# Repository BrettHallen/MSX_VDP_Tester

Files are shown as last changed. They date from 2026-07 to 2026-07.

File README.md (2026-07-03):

# Yamaha V99x8 Tester for MSX
Simple Arduino sketch & PCB to test if a V9958 is real.<br>

PCB is designed & Arduino sketch generated (by Claude) but nothing is tested or sanity checked yet (3/Jul/2026).<br>

Idea is to query the "identification number" of the chip from bits 1-5 of status register S#1:
- 0 = V9938
- 1 = V9948
- 2 = V9958
- 3 = V9968
- 4 = V9978

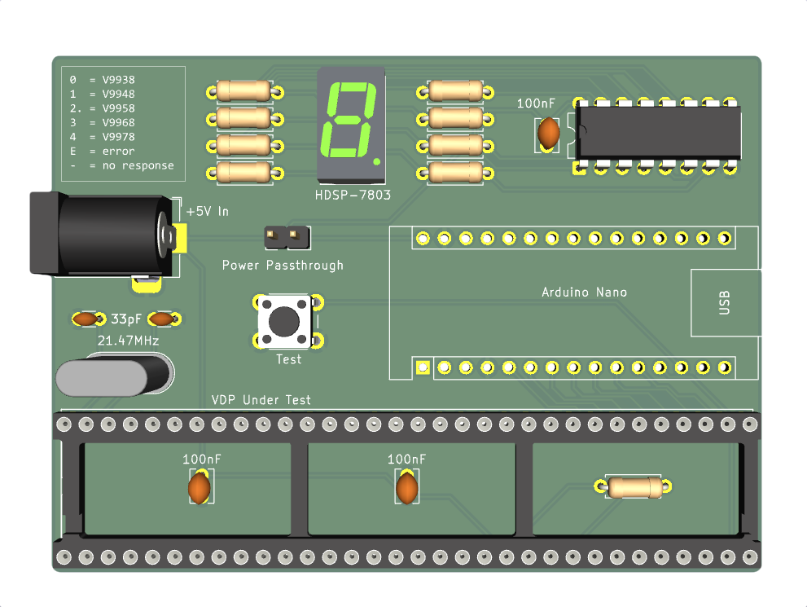
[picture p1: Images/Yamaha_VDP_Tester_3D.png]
3D of PCB


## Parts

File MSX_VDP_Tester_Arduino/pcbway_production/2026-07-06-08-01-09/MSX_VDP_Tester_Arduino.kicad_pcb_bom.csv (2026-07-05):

Designator | Quantity | Value | Footprint | Package | MPN | DNP | Mount_Type | Description | KiLib_Generator
A1 | 1 | Arduino Nano | Arduino_Nano |  |  |  | tht | Socket for Arduino Nano
C1, C2, C3 | 3 | 100nF | C_Disc_D3.8mm_W2.6mm_P2.50mm |  |  |  | tht | Unpolarized capacitor | capacitor/THT/other
C4, C5 | 2 | 33pF | C_Disc_D3.0mm_W1.6mm_P2.50mm |  |  |  | tht | Unpolarized capacitor | capacitor/THT/other
J1 | 1 | VDP Under Test | DIPS1905W50P178L5730H420Q64N |  |  |  | tht | Generic connector, double row, 02x32, counter clockwise pin numbering scheme (similar to DIP package numbering), script generated (kicad-library-utils/schlib/autogen/connector/)
J2 | 1 | +5V In | BarrelJack_Horizontal |  |  |  | tht | DC Barrel Jack
J3 | 1 | Power Passthrough | PinHeader_1x02_P2.54mm_Vertical |  |  |  | tht | Generic connector, single row, 01x02, script generated (kicad-library-utils/schlib/autogen/connector/) | connector/pin_header_socket
R1 | 1 | 10KΩ | R_Axial_DIN0207_L6.3mm_D2.5mm_P7.62mm_Horizontal |  |  |  | tht | Resistor | resistor/THT
R2, R3, R4, R5, R6, R7, R8, R9 | 8 | 470Ω | R_Axial_DIN0207_L6.3mm_D2.5mm_P7.62mm_Horizontal |  |  |  | tht | Resistor | resistor/THT
SW1 | 1 | Test | SW_PUSH_6mm |  |  |  | tht | Push button switch, generic, two pins
U1 | 1 | 74LS595 | DIP-16_W7.62mm |  |  |  | tht | 8-bit serial in/out Shift Register 3-State Outputs | package/DIP/legacy
U2 | 1 | HDSP-7803 | HDSP-7801 |  |  |  | tht | One digit 7 segment green, common cathode
Y1 | 1 | 21.47MHz | Crystal_HC49-U_Vertical |  |  |  | tht | Two pin crystal | crystal_resonator_oscillator

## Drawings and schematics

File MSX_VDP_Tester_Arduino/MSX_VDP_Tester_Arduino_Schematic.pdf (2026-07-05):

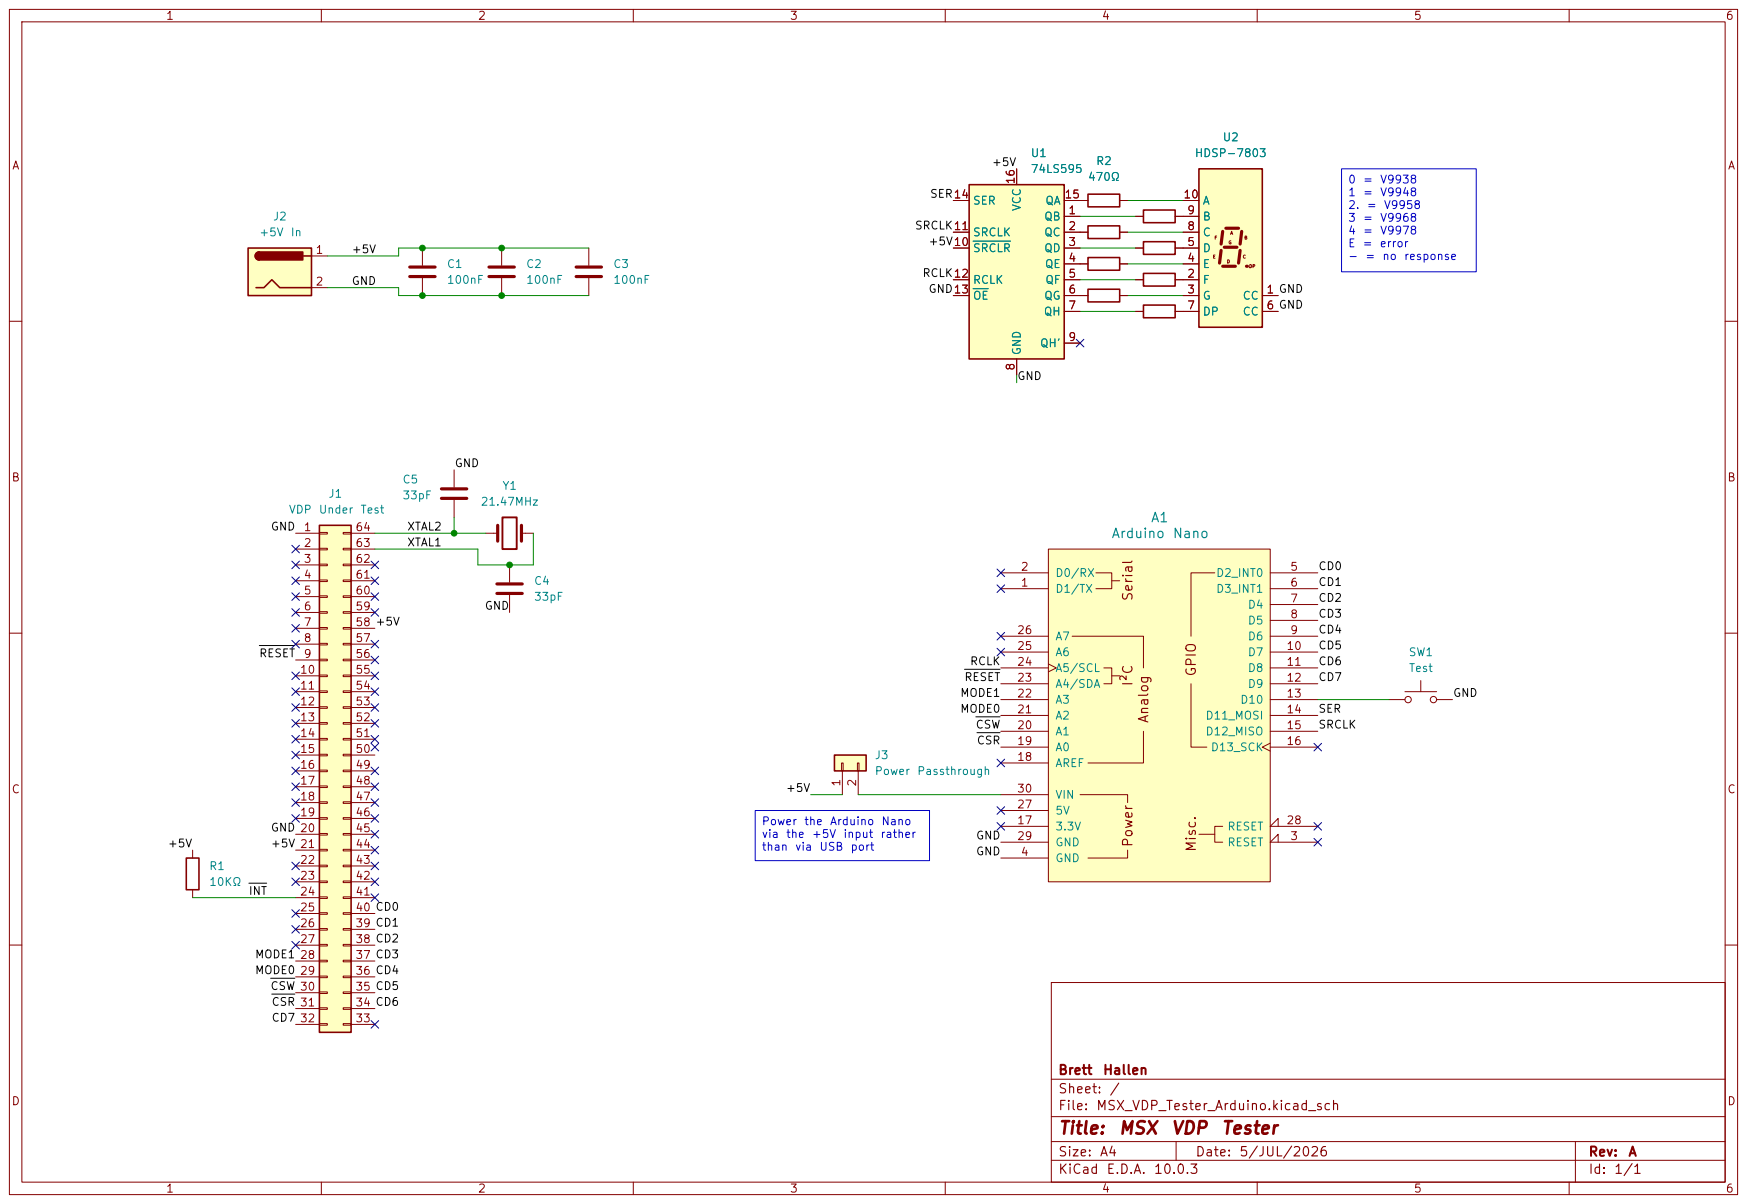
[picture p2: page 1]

SRCLR 10 SRCLK 11 RCLK 12 OE 13

E = error - = no response Power the Arduino Nano

via the +5V input rather
than via USB port

Brett Hallen
Sheet: /
File: MSX_VDP_Tester_Arduino.kicad_sch
Title: MSX VDP Tester

Size: A4 | Rev: A
KiCad E.D.A. 10.0.3 | Id: 1/1

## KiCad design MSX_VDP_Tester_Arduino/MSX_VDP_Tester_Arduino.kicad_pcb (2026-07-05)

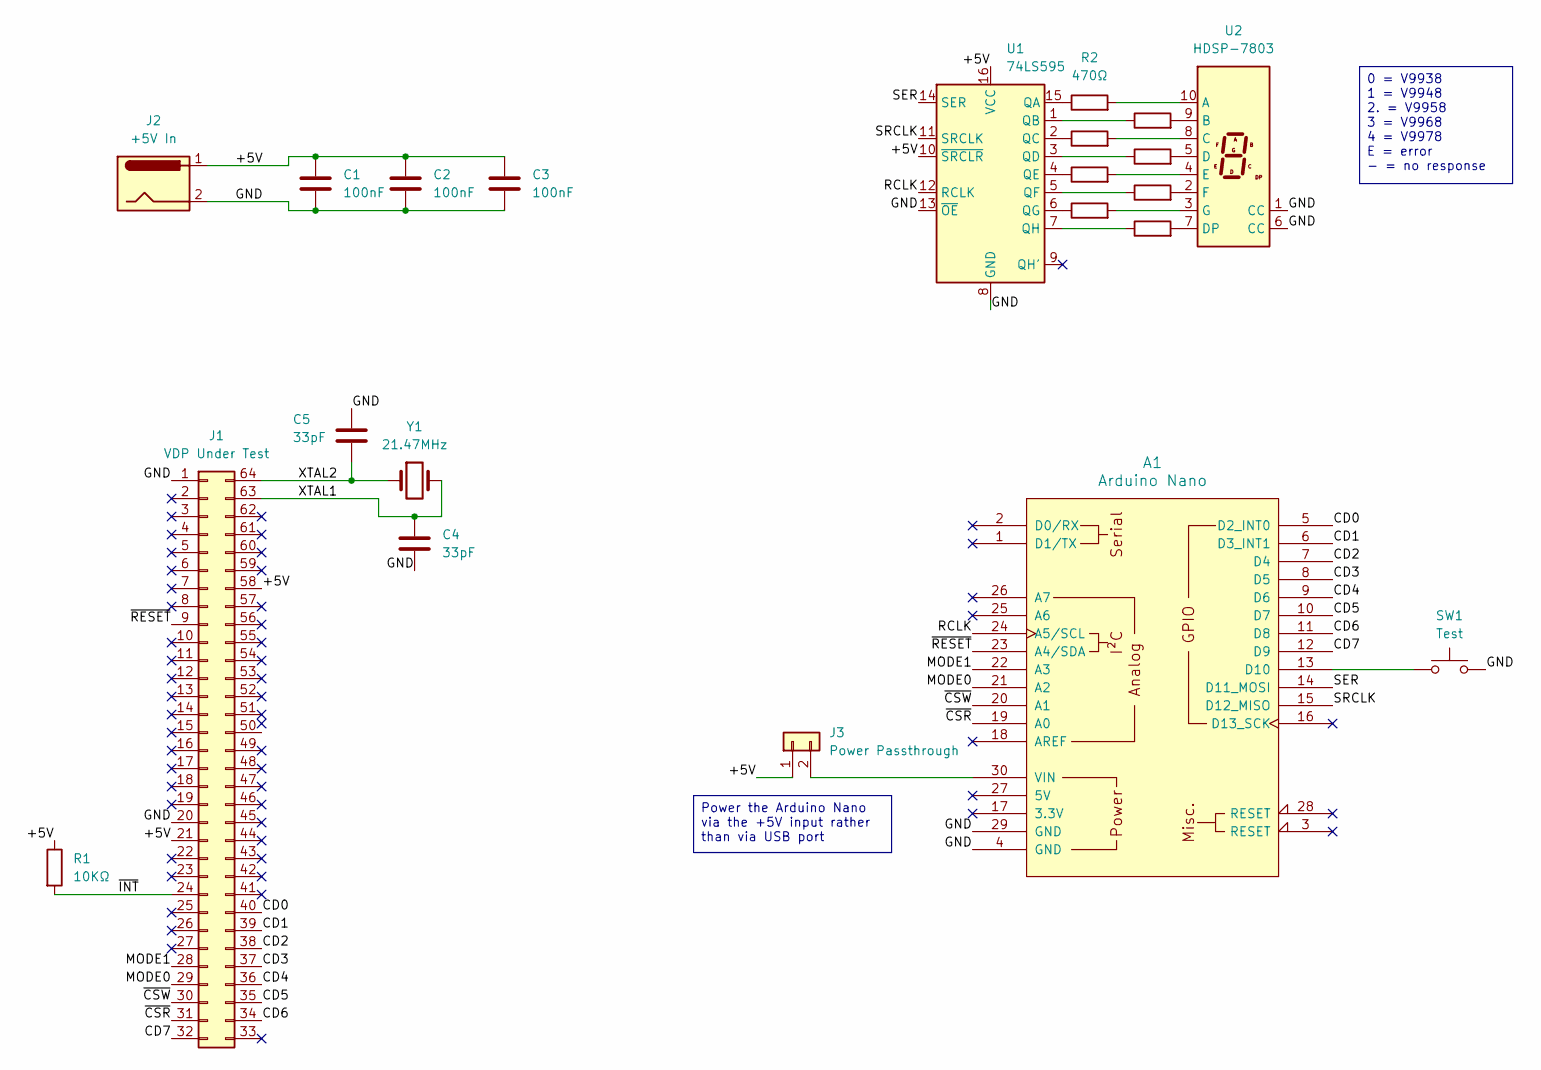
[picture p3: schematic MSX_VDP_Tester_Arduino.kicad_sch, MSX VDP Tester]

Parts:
A1: Arduino Nano; Arduino_Nano
C1, C2, C3: 100nF; C_Disc_D3.8mm_W2.6mm_P2.50mm
C4, C5: 33pF; C_Disc_D3.0mm_W1.6mm_P2.50mm
J1: VDP Under Test; DIPS1905W50P178L5730H420Q64N
J2: +5V In; BarrelJack_Horizontal
J3: Power Passthrough; PinHeader_1x02_P2.54mm_Vertical
R1: 10KΩ; R_Axial_DIN0207_L6.3mm_D2.5mm_P7.62mm_Horizontal
R2, R3, R4, R5, R6, R7, R8, R9: 470Ω; R_Axial_DIN0207_L6.3mm_D2.5mm_P7.62mm_Horizontal
SW1: Test; SW_PUSH_6mm
U1: 74LS595; DIP-16_W7.62mm
U2: HDSP-7803; HDSP-7801
Y1: 21.47MHz; Crystal_HC49-U_Vertical

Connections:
/+5V: C1.1, C2.1, C3.1, J1.21, J1.58, J2.1, J3.1, R1.1, U1.10 (~SRCLR), U1.16 (VCC)
/CD0: A1.5 (D2_INT0), J1.40
/CD1: A1.6 (D3_INT1), J1.39
/CD2: A1.7 (D4), J1.38
/CD3: A1.8 (D5), J1.37
/CD4: A1.9 (D6), J1.36
/CD5: A1.10 (D7), J1.35
/CD6: A1.11 (D8), J1.34
/CD7: A1.12 (D9), J1.32
/GND: A1.4 (GND), A1.29 (GND), C1.2, C2.2, C3.2, C4.2, C5.2, J1.1, J1.20, J2.2, SW1.2, U1.8 (GND), U1.13 (~OE), U2.1 (CC), U2.6 (CC)
/MODE0: A1.21 (A2), J1.29
/MODE1: A1.22 (A3), J1.28
/RCLK: A1.24 (A5/SCL), U1.12 (RCLK)
/SER: A1.14 (D11_MOSI), U1.14 (SER)
/SRCLK: A1.15 (D12_MISO), U1.11 (SRCLK)
/XTAL1: C4.1, J1.63, Y1.2
/XTAL2: C5.1, J1.64, Y1.1
/~CSR: A1.19 (A0), J1.31
/~CSW: A1.20 (A1), J1.30
/~INT: J1.24, R1.2
/~RESET: A1.23 (A4/SDA), J1.9
unnamed: A1.13 (D10), SW1.1
unnamed: A1.30 (VIN), J3.2
unnamed: R2.1, U1.15 (QA)
unnamed: R3.1, U1.1 (QB)
unnamed: R4.1, U1.2 (QC)
unnamed: R5.1, U1.3 (QD)
unnamed: R6.1, U1.4 (QE)
unnamed: R7.1, U1.5 (QF)
unnamed: R8.1, U1.6 (QG)
unnamed: R9.1, U1.7 (QH)
unnamed: R2.2, U2.10 (A)
unnamed: R3.2, U2.9 (B)
unnamed: R4.2, U2.8 (C)
unnamed: R5.2, U2.5 (D)
unnamed: R9.2, U2.7 (DP)
unnamed: R6.2, U2.4 (E)
unnamed: R7.2, U2.2 (F)
unnamed: R8.2, U2.3 (G)

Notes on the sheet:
Power the Arduino Nano via the +5V input rather than via USB port
0 = V9938 1 = V9948 2. = V9958 3 = V9968 4 = V9978 E = error - = no response

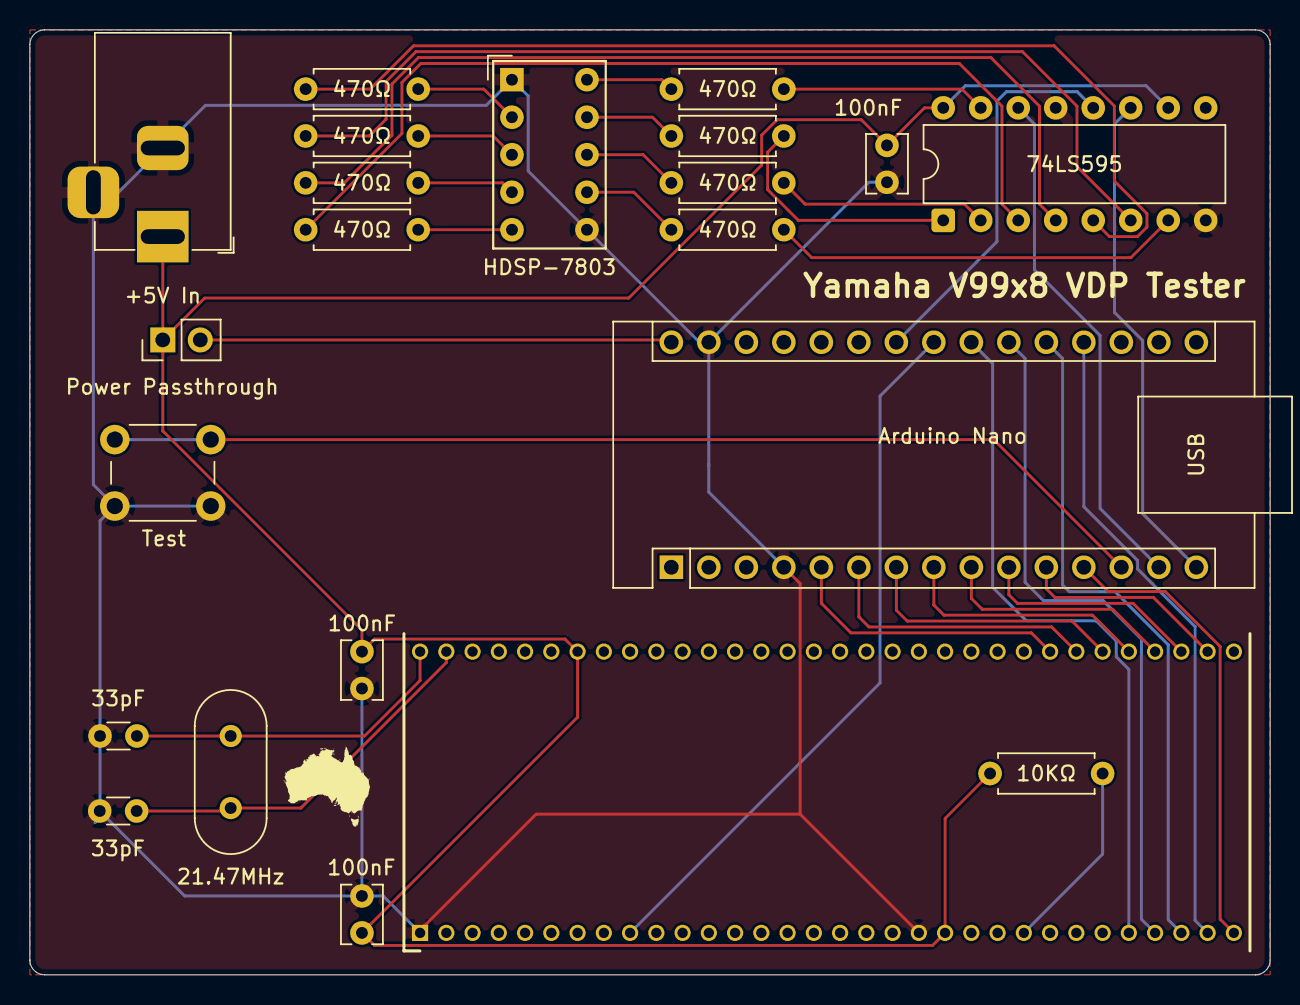
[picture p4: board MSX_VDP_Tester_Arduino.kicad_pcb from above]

Board: 2 copper layers, 84.0 x 64.0 mm, 22 parts (0 on the bottom side), 39 nets.

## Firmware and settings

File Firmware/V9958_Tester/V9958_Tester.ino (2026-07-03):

/* NOTE! Generated by Claude */
/* Not yet reviewed, cleaned up or even tested */
/* Brett Hallen, 3/Jul/2026 */

/*
 * ============================================================================
 *  V9958 / V9938 VDP Authenticity Tester  --  ARDUINO UNO / NANO (ATmega328P)
 *
 *  Uno and Nano share the ATmega328P, so the pin map and direct-port code are
 *  identical. NOTE: on the Nano, A6/A7 are ADC-input-only and CANNOT be used
 *  as digital I/O -- do not move any control line onto them.
 * ============================================================================
 *
 *  Reads the Yamaha VDP's built-in version ID (status register S#1, bits 1-5,
 *  the "ID#" field per datasheet section 5.2) to tell a genuine V9958 apart
 *  from a relabeled V9938 or a dead / non-responding chip.
 *
 *      ID = 0  ->  V9938
 *      ID = 1  ->  V9948   (rare Korean variant)
 *      ID = 2  ->  V9958   <-- a genuine MSX2+ chip returns this
 *      ID = 3  ->  V9968
 *      ID = 4  ->  V9978
 *
 *  Press the push button to run a test; results print to the Serial Monitor
 *  at 115200 baud.
 *
 * ----------------------------------------------------------------------------
 *  WHY THIS VERSION USES DIRECT PORT I/O (important)
 * ----------------------------------------------------------------------------
 *  Datasheet 7.3.5 gives /CSR and /CSW a MAXIMUM pulse width of 2000 ns.
 *  A normal digitalRead() of 8 pins takes ~30 us and would violate that.
 *  So the data bus and strobes are driven with direct AVR port registers,
 *  keeping every strobe pulse well under a microsecond.
 *
 *  CONSEQUENCE: the pin assignments below are NOT freely reassignable -- they
 *  are chosen so the data bus lands on specific AVR port bits. If you move a
 *  pin you must update the bit math in readDataBus()/writeDataBus().
 *
 * ----------------------------------------------------------------------------
 *  CLOCK REQUIRED  (the VDP does nothing until its XTAL input is clocked)
 * ----------------------------------------------------------------------------
 *  The Arduino cannot generate this clock. Use ONE of two mutually exclusive
 *  options; frequency must be in the 20.26 - 22.55 MHz range (datasheet 7.3.1),
 *  and 21.477 MHz (standard MSX) is ideal:
 *
 *  OPTION A - CRYSTAL (uses the VDP's on-chip oscillator; datasheet section 8
 *             reference circuit). A passive crystal cannot run on its own, so
 *             it connects ACROSS both pins and relies on the internal amp:
 *                 XTAL1 (63) --+--[ 21.477 MHz crystal ]-+-- XTAL2 (64)
 *                              |                         |
 *                             ===  C                    ===  C
 *                              |                         |
 *                             GND                       GND
 *             Use a PARALLEL crystal with a specified load cap CL (e.g. 18pF)
 *             and size each C ~= 2*(CL - Cstray), Cstray ~3-5pF: CL=18pF -> ~27pF,
 *             CL=20pF -> ~33pF. (A series-resonant crystal will run slightly high
 *             but still works here.) The fuller V9938 data book appendix "Clock
 *             oscillation internal circuitry" gives Yamaha's recommended network.
 *
 *  OPTION B - ACTIVE OSCILLATOR MODULE (self-powered "can"; replaces the
 *             on-chip oscillator, so there is NO crystal and NO load caps):
 *                 module output -> XTAL1 (63),   XTAL2 (64) -> open
 *             Robust on a breadboard. The datasheet is terse on the external-
 *             clock path (7.3.1 lists both XTAL1 and XTAL2), so if the liveness
 *             check reports NO RESPONSE, try driving XTAL2 instead, or use A.
 *
 * ----------------------------------------------------------------------------
 *  WIRING  (VDP pin numbers from the V9958 Technical Data Book)
 * ----------------------------------------------------------------------------
 *    CD0(40)->D2  CD1(39)->D3  CD2(38)->D4  CD3(37)->D5
 *    CD4(36)->D6  CD5(35)->D7  CD6(34)->D8  CD7(32)->D9
 *        (CD0..CD5 = PORTD bits 2..7,  CD6..CD7 = PORTB bits 0..1)
 *    /CSR(31)->A0   /CSW(30)->A1   MODE0(29)->A2   MODE1(28)->A3
 *        (order matches V9958 pins 31..28 so traces run straight, no vias)
 *    /RESET(9)->A4                       (strobes/mode/reset = PORTC 0..4)
 *    Button -> D10 to GND (internal pull-up)     LED -> D13 (onboard)
 *    7-seg via 74HC595 (pin names shown NXP / TI). Nano -> 595:
 *        D11 -> pin14  DS/SER    (serial data)
 *        D12 -> pin11  SHCP/SRCLK (shift clock)
 *        A5  -> pin12  STCP/RCLK  (latch)
 *    595 static pins: pin16 VCC->+5V   pin8 GND->GND
 *        pin13 /OE->GND (outputs enabled)   pin10 /MR->+5V (no reset)
 *        pin9 Q7S/QH' (serial-out) -> open (only used to chain a 2nd digit)
 *    595 outputs -> COMMON-CATHODE segments, each via ~470R resistor
 *    (HDSP-7803 green: ~5 mA/seg, ~30 mA worst case through the 595)
 *    (NOTE: Q0 is pin 15, NOT next to Q1..Q7 which are pins 1..7):
 *        pin15 Q0->a  pin1 Q1->b  pin2 Q2->c  pin3 Q3->d
 *        pin4  Q4->e  pin5 Q5->f  pin6 Q6->g  pin7 Q7->DP
 *        digit common cathodes -> GND. 100nF across 595 VCC/GND.
 *    Display: 0-4 = VDP ID, DP lit = genuine V9958, '-' = no response,
 *        'E' = error (unstable or unrecognized ID).
 *    XTAL1(63) / XTAL2(64) -> clock: see CLOCK REQUIRED above (crystal across
 *        both pins, OR an oscillator module into XTAL1 with XTAL2 open)
 *    VDD(58)+VDD/DAC(21) -> +5V     GND(1)+GND/DAC(20) -> GND
 *    /INT(25), /WAIT(26), all VRAM/RGB/sync/color-bus pins -> open
 *
 *  Power the VDP from a bench 5V supply (up to 230 mA, datasheet 7.3.2),
 *  common ground with the Uno. VRAM is not required for an ID read.
 *
 *  Port select truth table (MODE1,MODE0):
 *    00 = VRAM   01 = status read / register write (used here)
 *    10 = palette   11 = register pointer / indirect
 * ============================================================================
 */

#include <avr/io.h>

// -------- PORTC bit positions for control lines (A0..A4) --------
// Order chosen to match the V9958 pin sequence (31,30,29,28) so the PCB
// traces run straight with no crossings/vias.
#define BIT_CSR    0   // A0  -> /CSR   (read strobe,  active LOW)
#define BIT_CSW    1   // A1  -> /CSW   (write strobe, active LOW)
#define BIT_MODE0  2   // A2  -> MODE0  (port-select bit 0)
#define BIT_MODE1  3   // A3  -> MODE1  (port-select bit 1)
#define BIT_RESET  4   // A4  -> /RESET (active LOW)

#define PIN_BUTTON 10  // PB2, INPUT_PULLUP
#define PIN_LED    13  // PB5, onboard LED

// -------- 7-segment display via one 74HC595 (3 pins) --------
// Common-cathode single digit. 595 Qn -> segment via resistor; commons -> GND.
//   Q0->a  Q1->b  Q2->c  Q3->d  Q4->e  Q5->f  Q6->g  Q7->decimal point
#define SEG_DATA  11   // D11 -> 595 DS   (pin 14)
#define SEG_CLK   12   // D12 -> 595 SHCP (pin 11, shift clock)
#define SEG_LATCH A5   // A5  -> 595 STCP (pin 12, latch)
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

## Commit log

2026-07-05 Initial version for testing
    [MSX_VDP_Tester_Arduino.kicad_pcb, MSX_VDP_Tester_Arduino.kicad_pcb_bom.csv, MSX_VDP_Tester_Arduino.kicad_pcb_positions.csv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]
2026-07-05 Minor PCB change
    [MSX_VDP_Tester_Arduino.kicad_pcb, MSX_VDP_Tester_Arduino.kicad_pcb_bom.csv, MSX_VDP_Tester_Arduino.kicad_pcb_positions.csv]
